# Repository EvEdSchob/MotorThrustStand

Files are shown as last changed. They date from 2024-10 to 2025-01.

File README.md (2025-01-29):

# MotorThrustStand
This motor thrust stand is an open an extensible hardware testing platform for the evaluation of small electric propulsion systems such as those used in remote control airplanes, helicopters, and drones. It was developed for implementation and use within an existing wind tunnel in the unmanned aerial vehicle laboratory at Western Michigan University by myself and my senior design partner Joshua Kraeteur.

The completed project inludes: 

- A JavaFX application comprising the user interface and data processing functionality
- KiCAD PCB design files for construction of the data capture system
- A TeensyDuino program for receiving UI commands and handling data capture and transmission
- 3D Print files for the PCB enclosure as well as mounting hardware for the pitot tubes
- A user manual with setup instructions and calibration proceedures
  
The system incorporates the following set of sensors:

- Two Pitot Tubes
- Voltage Sensor
- Current Sensor
- Tachometer
- Load Cell

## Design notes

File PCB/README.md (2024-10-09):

This folder includes the original KiCAD files for the PCB Design as well as the Gerber files used for PCB production.

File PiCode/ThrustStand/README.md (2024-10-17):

#PiCode
_A JavaFX application for controlling a Teensy 4.0 over USB serial link_

#Libraries
Built using LibericaJDK 21 LTS
Requires jSerialComm in /lib

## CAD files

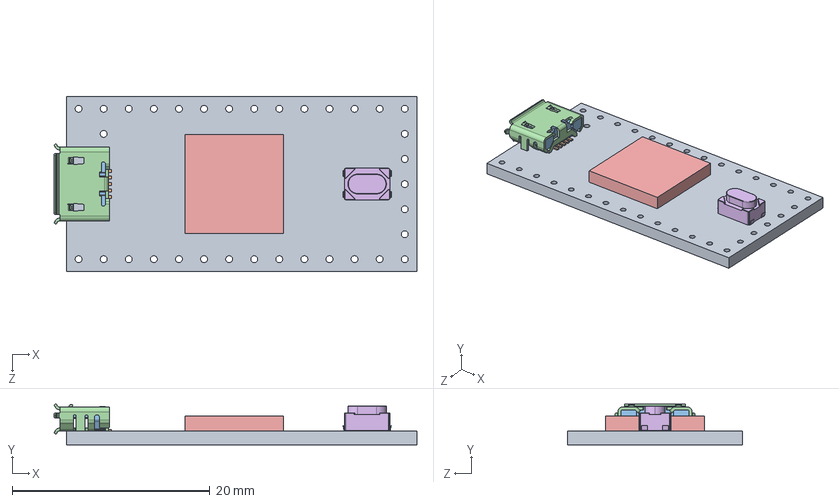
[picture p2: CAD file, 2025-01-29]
PCB/Component Libraries/teensy.pretty-master/Teensy_4.0_Assembly.STEP
36.8 x 4.12 x 17.7 mm
Teensy_4.0_PCB
Micro USB-B Female 5Pin SMD
NXP iMXRT1062
SKRPACE010 v4

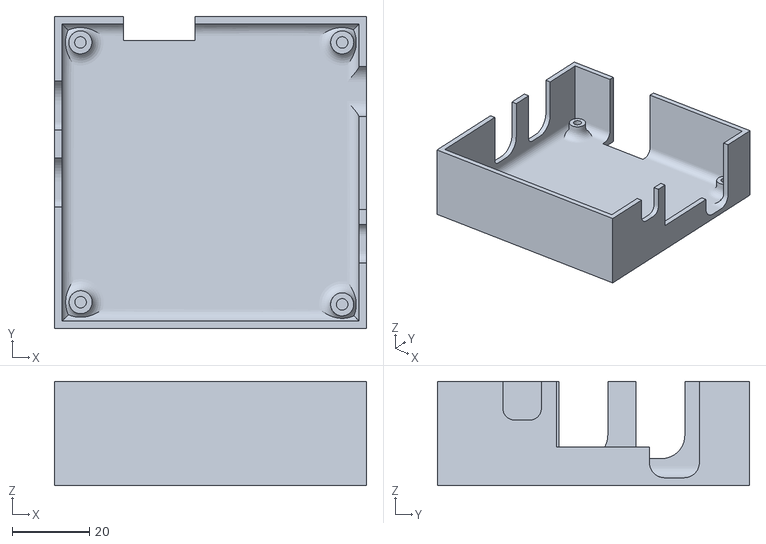
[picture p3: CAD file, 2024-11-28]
3D Print Files/Case Lower.stl
81.0 x 81.0 x 27.0

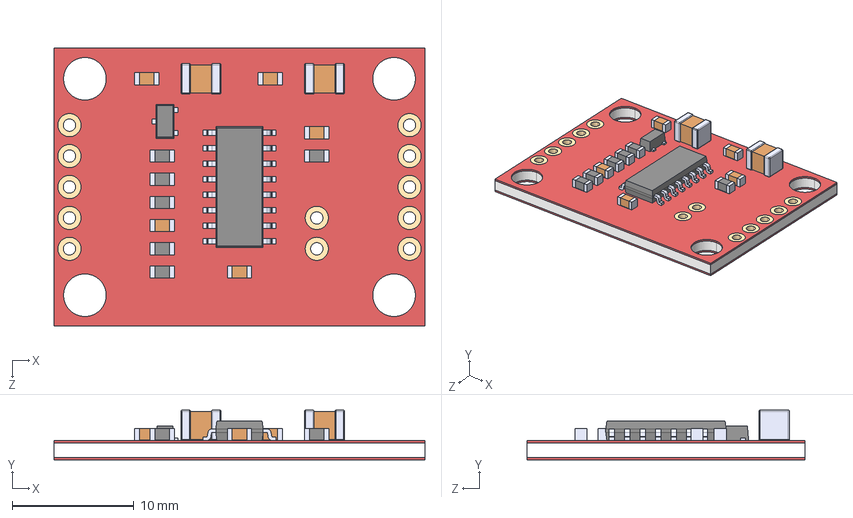
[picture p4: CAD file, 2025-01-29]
PCB/Component Libraries/SEN_13879/SEN-13879.step
30.5 x 4.10 x 22.9 mm

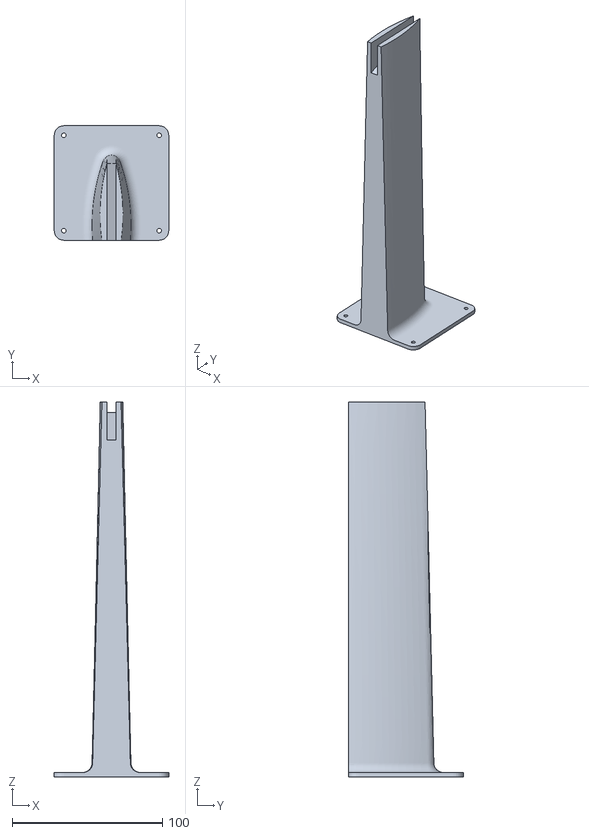
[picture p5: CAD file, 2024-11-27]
3D Print Files/Pitot Plinth Forward.stl
76.2 x 76.2 x 249.4

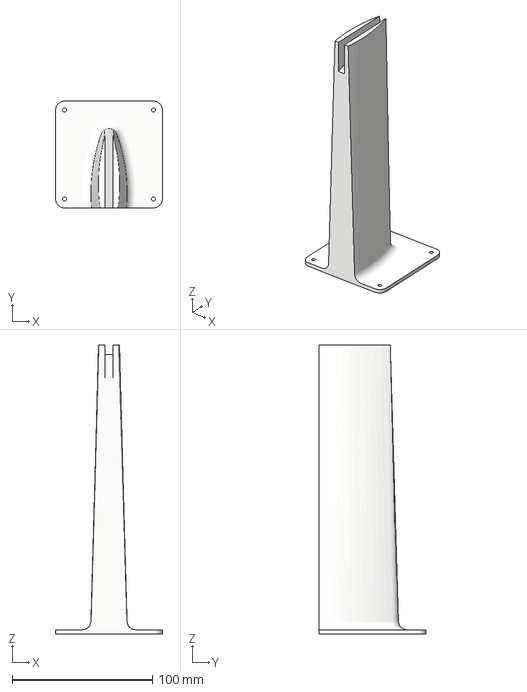
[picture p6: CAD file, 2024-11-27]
3D Print Files/Pitot Plinth Rear.3mf
76.2 x 76.2 x 206.2 mm

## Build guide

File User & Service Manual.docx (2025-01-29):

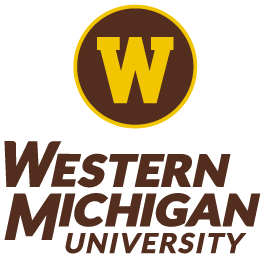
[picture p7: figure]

# Motor Thrust Stand User and Service Manual

# Hardware

Datasheets for each component are included in the Appendix

## Processing

Raspberry Pi 5

Teensy 4.0

## Sensors

Voltage Divider – A simple variable voltage divider nominally calibrated to 10:1.

Differential Pressure Sensors – Two MP3V5010DP differential pressure sensors connected to a pair of pitot-static tubes placed in the incoming and wake airflow.

Load Cell ADC – HX711 24-bit load cell amplifier breakout board from Spark Fun.

Current Sensor – One ACS758ECB-200U current sensor measuring up to 200 amperes of continuous current and capable of handling 1200 amperes of current in bursts of up to 1 second.

# Setup

## Installation

The software is provided with an installation script which will install all necessary packages and libraries. It will compile the relevant class files, download the WMU logos found on https://wmich.edu/brand/visualidentity/logo and create a desktop shortcut for the thrust stand software.

1. Download the repository from GitHub: https://github.com/EvEdSchob/MotorThrustStand
  a. Clone the repository using a git client or download it as a zip file
  b. If it was downloaded as a zip extract the file to a local folder on the Raspberry Pi
2. Navigate to the directory: MotorThrustStand/PiCode/ThrustStand in a terminal window
3. Run the command below to make the script executable sudo chmod +x thruststand-install.sh
4. Enter the command below to start the installation process sudo ./thruststand-install.sh
5. If the installer runs successfully the application can be executed in three different ways:
  a. Run the command thruststand in the terminal window. This will provide debugging output to the terminal.
  b. Click the shortcut icon on the desktop
  c. In the Raspberry Pi OS menu navigate to Accessories > ThrustStand

## Un-installing

To uninstall the software simply run: sudo ./thruststand-install.sh --uninstall

# User Interface

## Launcher

- This is the first screen shown to the user when the software launches

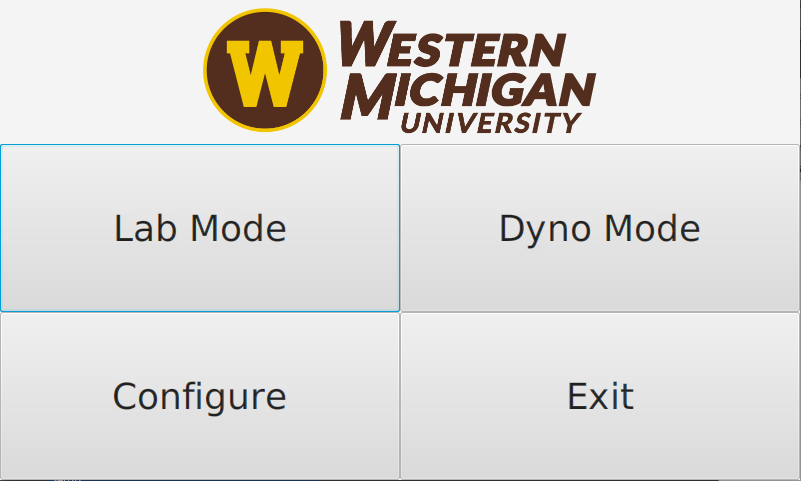
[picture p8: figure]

Figure 1: Launcher Screen

- Lab Mode – Launches the Lab Mode Screen
- Dyno Mode – Launches the Dyno Mode Screen
- Configure – Launches the Configuration Screen
- Exit – Closes the program

## Lab Mode

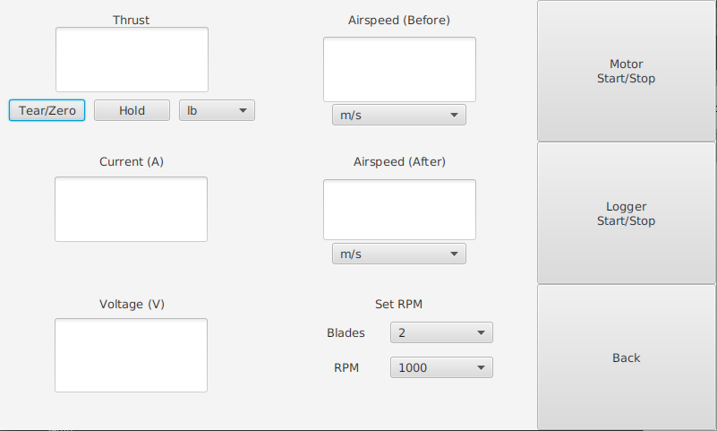
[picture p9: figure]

Figure 2: Lab Mode Screen

- Thrust – Displays the live thrust value in the selected unit
  a. Tear/Zero – “Zeroes” the thrust measurement value
  b. Hold – Freezes the user display for easy reading
  c. Units – Selects the unit of thrust measurement: Newtons, Pounds, Kilograms
- Current – Displays the live current value in Amperes
- Voltage – Displays the live voltage value in Volts
- Airspeed (Before) –
- Airspeed (After) –
- Set RPM
  d. Blades – Sets the number of blades on the propeller
  e. RPM – Sets the RPM setpoint for the PID controller on the Teensy
- Motor Start/Stop – Enables and Disables commands to the speed controller. Sets throttle to zero when disabled.
- Logger Start/Stop – Activates and Deactivates data logging. Creates a new file on disk each time it is enabled and finalizes said file when disabled.

## Dyno Mode

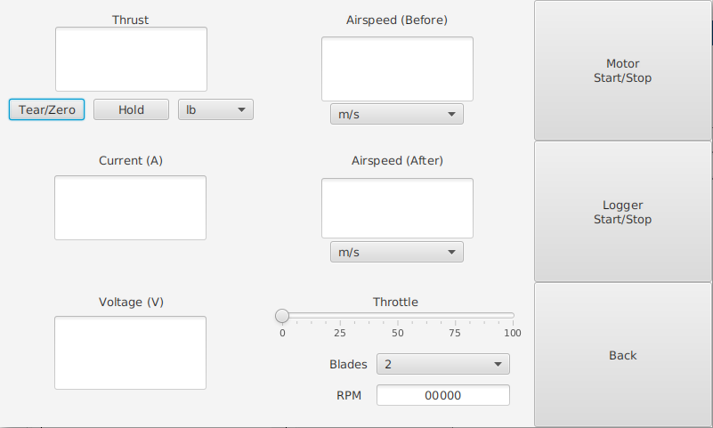
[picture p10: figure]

Figure 3: Dyno Mode Screen

- Most controls are identical to those found in Lab Mode. Refer to the Lab Mode section for details of each shared control.
- Throttle – The slider directly controls the throttle percentage between 0% and 100%
- RPM – Displays the live RPM measurement

## Configuration

- Save Calibration – Stores calibration constants for all sensors in a local file
- Load Calibration – Retrieves calibration constants from the data file
- Reset to Defaults – Loads default calibration constants from the hard-coded values
- Back – Exits the calibration screen

### Serial

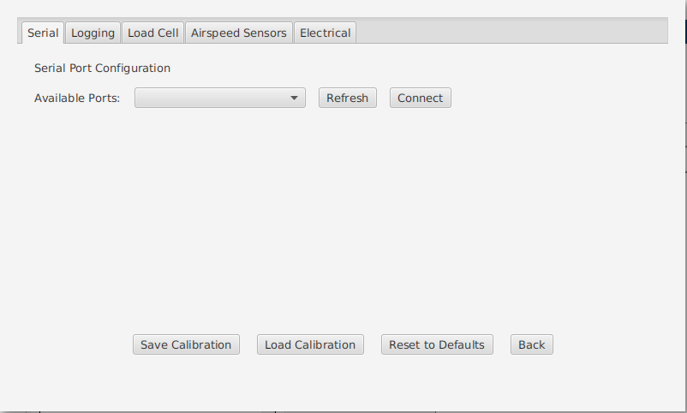
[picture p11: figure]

Figure 4: Configuration Screen - Serial Tab

- The configuration window automatically opens in the serial tab
- Ports Dropdown – Lists the available serial devices
- Refresh – Refreshes the list of serial devices
- Connect – Attempts to establish connection with the selected serial device

### Logging

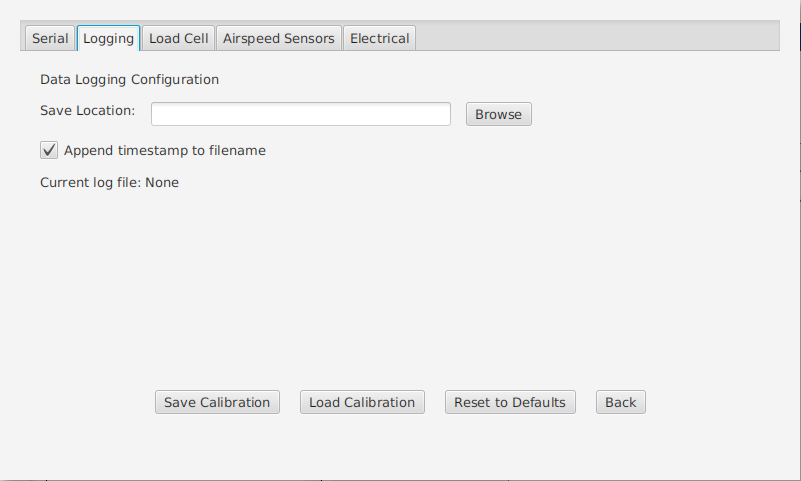
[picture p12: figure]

Figure 5: Configuration Screen - Logging Tab

- Save Location – Shows the path to the location where logging files will be saved
- Browse – Launches a directory chooser window to select where the log file will be saved
- Current log file: - Displays the name of the log file to be saved

### Load Cell

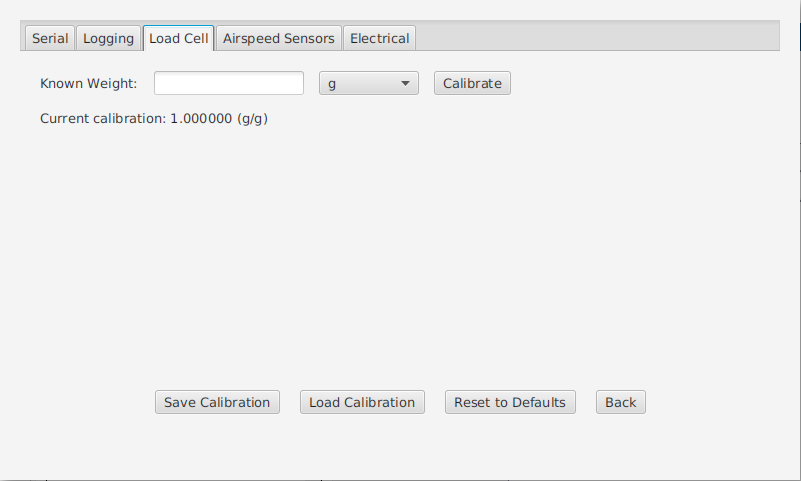
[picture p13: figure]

- Known Weight – Enter the current weight for calibration purposes
- Unit Dropdown – Selects the unit of the weight being used for calibration
- Calibrate – Calculates the new calibration constant for the load cell
- Current Calibration – Displays the current calibration constant

### Airspeed Sensors

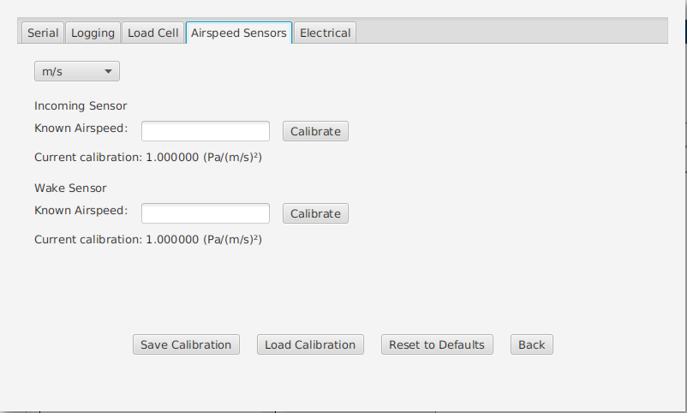
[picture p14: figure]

- Unit Dropdown – Selects the unit for airspeed calibration
- Known Airspeed – Textboxes for entering the externally measured air speed
- Calibrate – Buttons initiate the calibration constant calculation

### Electrical

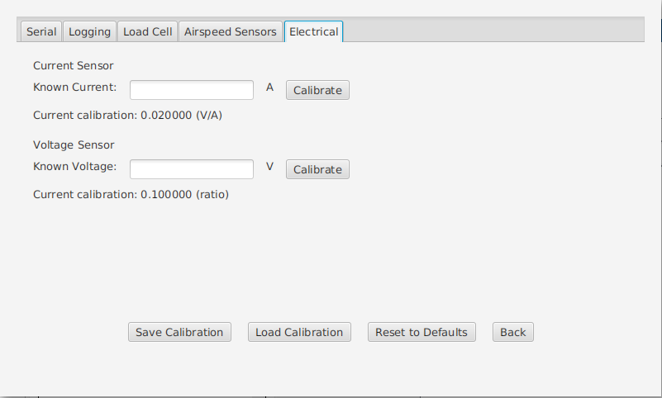
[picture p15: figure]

- Known Current – Textbox for entering the externally measured current value
- Known Voltage - Textbox for entering the externally measured voltage value
- Calibrate – Buttons initiate the calibration constant calculation

# Usage

## Startup

1. Turn on the power strip under the wind tunnel to power the device
2. Wait for the system to start up and come to the desktop
3. Launch the software:
  a. Run the command thruststand in the terminal window. This will provide debugging output to the terminal.
  b. Click the shortcut icon on the desktop
  c. In the Raspberry Pi OS menu navigate to Accessories > ThrustStand
4. Press the Configure button on the main launcher window.
5. In the Serial tab, use the drop-down menu to select the correct serial device then press the Connect button.
  a. If no device is found ensure that the USB cable is properly connected between the Teensy and the user interface then press the Refresh button.
6. (Optional) Press the Load Calibration button to load the previously saved calibration values. Skipping this step will cause the software to use the default calibration values from the software.
  a. If the system needs to be recalibrated, please see the calibration instructions on page 6.
7. (Optional) Switch to the Logging tab and browse the filesystem for a location to save the logging file. If no alternate location is selected, files will be saved to the user’s home folder. NOTE: A log file will only be created if the Logger Start/Stop button is pressed within either Lab or Dyno mode.
8. Press the Back button to return to the launcher.
9. Press the Lab Mode or Dyno Mode button to enter the desired mode.

## Shutdown

1. From either mode or the Configuration screen press the Exit button to return to the Launcher.
2. Press the Exit button on the launcher to close the ThrustStand software.
3. In the Raspberry Pi OS Menu select Shutdown… > Shutdown to halt the Raspberry Pi.
4. Turn off the power strip under the thrust stand to fully power the system down.

# Calibration

## Requirements

Before beginning calibration ensure that all of the hardware listed below is available and in working order.

- Mouse
- Keyboard
- Multimeter with DC Voltage, Resistance, and Current modes
- Current Calibration Harness
- Anemometer
- Tachometer

## Voltage Divider

1. Disconnect the USB Cable from the Teensy microcontroller in the sensor package.
2. Open sensor package case
3. Remove Teensy microcontroller
  a. This prevents damage if the input voltage is above 3.3v and the trim potentiometer is adjusted incorrectly.
4. Attach a battery or other power source to the input of the sensor package
5. Measure the input voltage by placing the positive probe of a multimeter on one leg of the current sensor and the negative probe on the ground terminal as shown in Figure 6. Record this voltage.

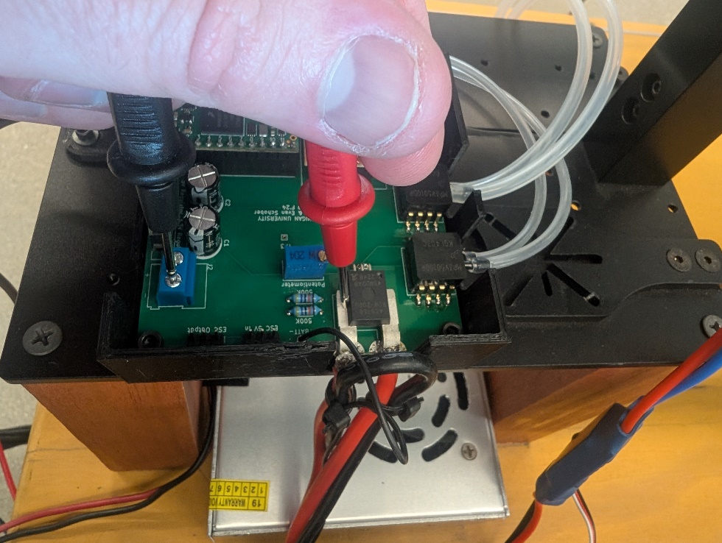
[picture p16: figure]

Figure 6: Input Voltage Measurement

6. Measure the output from the voltage divider by placing the positive probe of the multimeter on TP3 on the circuit board and the negative probe in the same location described in step 4. Record this voltage.

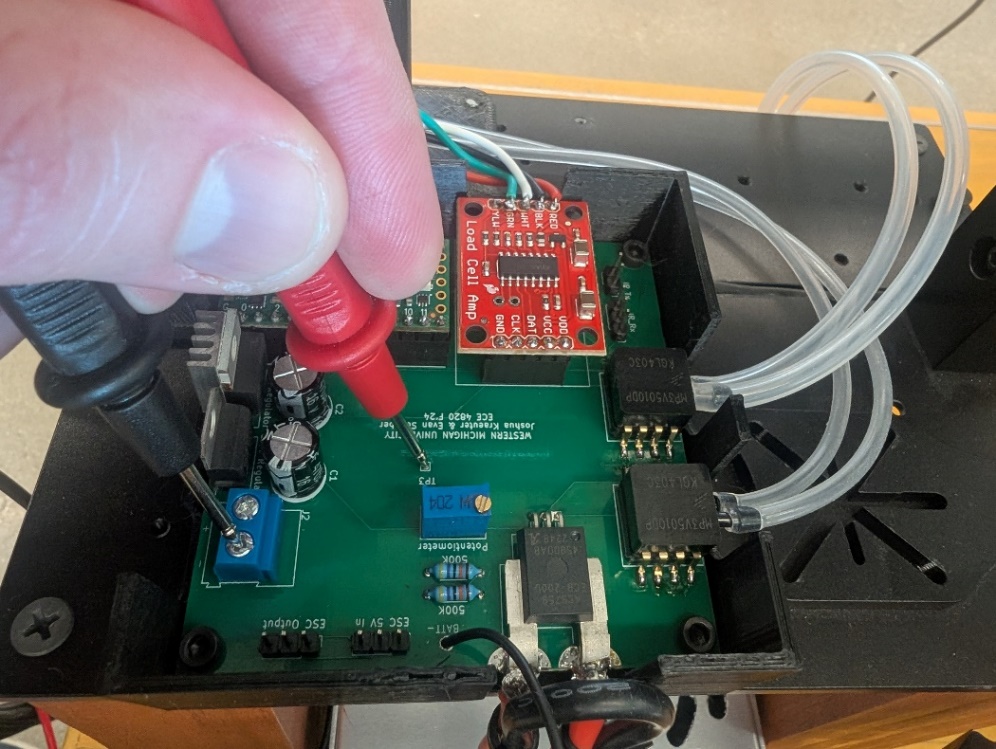
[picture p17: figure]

Figure 7: Voltage Divider Measurement

7. For a nominal configuration, (10:1 divider ratio) adjust the blue trim potentiometer so that the output voltage is one tenth of the input voltage.
  a. E.g. An input voltage of 12.19 volts results in a TP3 voltage of approximately 1.219 volts as shown below

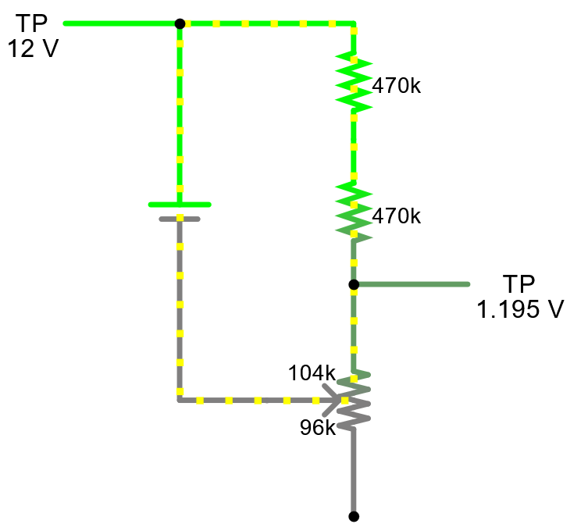
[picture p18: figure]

  b. This will allow voltages of up to 33v to be safely measured by the device.
  c. Higher voltages may be measured as necessary by re-calibrating the potentiometer for a higher divider ratio.
8. Once the trim potentiometer has been correctly adjusted, place the Teensy back into its slot with the USB port facing out.
9. Reconnect the USB cable to the micro USB port on the Teensy and one of the ports on the Pi
10. Start up the user interface and enter the Configuration menu.
11. In the Serial tab select the correct serial device and press the Connect button.
12. Switch to the Electrical tab.
13. Enter the measured battery voltage into the Known Voltage field and press the Calibrate button. This will cause the code to calculate the new divider ratio. NOTE: Please verify that the calculated value matches the expected value before continuing.
14. Press the Save Calibration button to save to the local file.

## Current Sensor

1. Start the User Interface, start the ThrustStand software and enter the Configuration mode.
2. In the Serial tab select the correct serial device from the dropdown and press the Connect button.
3. Use a multimeter in voltage mode to record the output voltage of the power source.
4. Measure the resistance of the Current Calibration Harness by connecting it to a multimeter in resistance mode with the shorting plug inserted. NOTE: It should be close to 10 ohms.

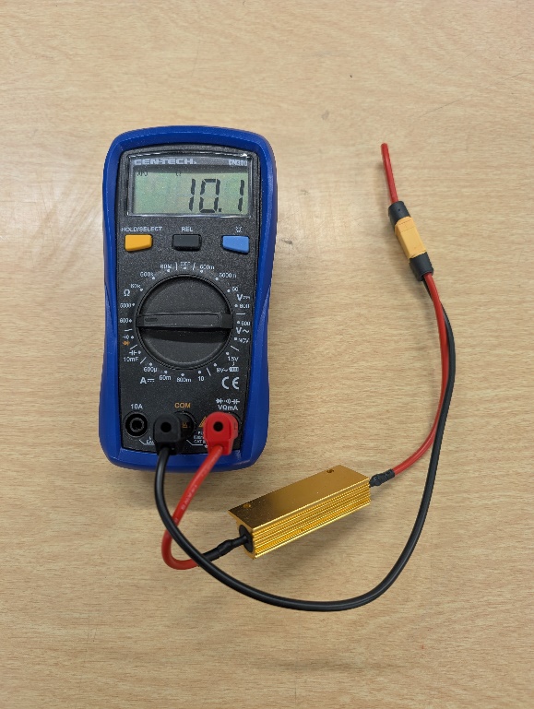
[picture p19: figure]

Figure 8: Current Harness Testing

5. Remove the shorting plug from the calibration harness and set it aside.
6. Connect the current harness to the output wire from the sensor package.

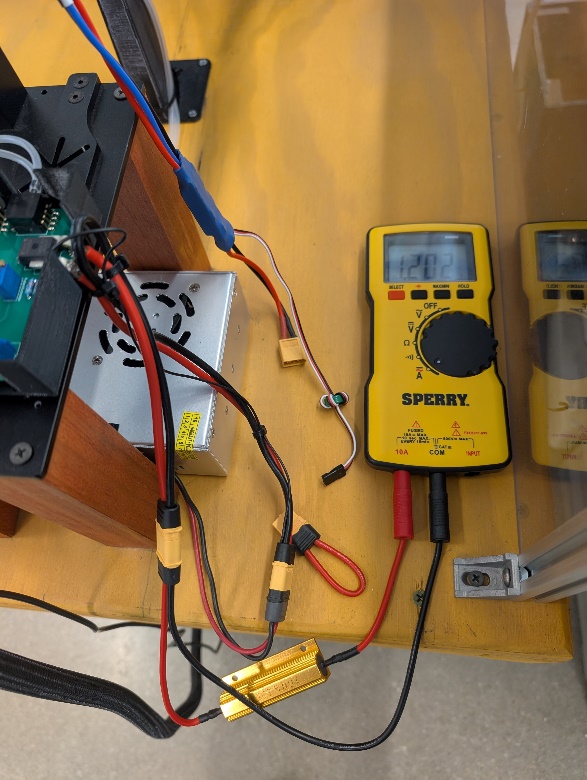
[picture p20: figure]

Figure 9: Current Calibration

7. Connect the power source to the input wire on the sensor package. NOTE: Do not leave the system connected in this configuration for extended periods of time or the resistor will become dangerously hot!
8. Enter the current value shown on the multimeter into the Known Current: field in the user interface and press the Calibrate button.
9. Press the Save Calibration button to save to the local file.
10. Disconnect the power source or the current calibration harness.

# Appendix

## Errata

1. External power is not needed for the sensor package board. The Teensy supplies sufficient voltage out through the Vin when receiving USB power to supply both regulators such that all onboard components are supplied correctly. Powering the board from the external source will cause both the 5v regulator and the Teensy to overheat.
2. There is a wire soldered to the bottom of the PCB which provides a signal ground for the voltage measurement. If this wire breaks or is removed voltage measurement will be erratic.
3. The MP3V5010DP sensor range is too great for the sensitivity of the Teensy’s ADC. These sensors have a maximum pressure differential of 1.45psi. The calculated resolution of the system is as follows:
- 2.21 meters per second
- 4.96 miles per hour
- 7.25 feet per second
- 7.95 kilometers per hour

This is the theoretical limit for the smallest measurements that can be made by the pitot system. More precise measurements would require a sensor with a narrower maximum range and/or an ADC with a higher bit-depth.

4. At present, no method exists to calibrate the RPM measurement from within the user interface.
5. An established method for calibrating the load cell has not been developed.
6. The Tear/Zero button in both Lab and Dyno mode temporarily resets the display back to the value “0” but does not “zero” the value of the load cell measurement.

## Datasheets

Datasheets for all sensors will be provided on the subsequent pages.

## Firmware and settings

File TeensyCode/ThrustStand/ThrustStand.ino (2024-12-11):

#include <Wire.h>
#include <HX711.h>

const int LED_PIN = 13; //On-board LED

//Pin Definitions
const int PITOT_FRONT = A0;
const int PITOT_REAR = A1;
const int I_SENS = A2; //Current Sensor
const int V_SENS = A3; //Voltage Sensor
const int HX711_DAT = 18;
const int HX711_CLK = 19;
const int IR_RECIV = 5;
const int ESC_PIN = 2;

//HX711 setup
HX711 loadCell;

//Speed Controller output
const float PWM_FREQ = 50.0f; //50Hz output for standard RC control
const int PWM_RES = 12; //12-bit PWM resolution
const int MIN_PULSE = 205; //~1000us at 50Hz
const int MAX_PULSE = 410; //~2000us at 50Hz

const unsigned long SEND_INTERVAL = 20; //Send interval in ms. 20ms = 1/50th of a second

//Serial control input buffer variables
String inputBuffer = "";
bool msgRDY = false;

//Serial send timer
unsigned long lastSendTime = 0;

//Tachometer variables
volatile unsigned long lastPulseTime = 0;
volatile unsigned long pulseCount = 0;
unsigned long lastRPM = 0;
const unsigned long RPM_CALC_INTERVAL = 100000; //Calculate RPM every 100ms
int numBlades = 2; //Default to 2 blade propeller
float currentRPM = 0.0;
const unsigned long RPM_TIMEOUT = 2000000; //Timeout RPM to 0 after 2 seconds

//Debounce the interrupt
const unsigned long DEBOUNCE_MICROS = 1000; //1ms debounce (May need to be shorter)
volatile unsigned long lastInterruptTime = 0;
unsigned long lastRPMcalc = 0; // Added missing variable declaration

// Global variables for control modes and PID
bool motorEnabled = false;
String currentMode = "NONE"; // Default to LAB mode
float targetRPM = 0;

// PID constants
const float KP = 0.1;  // Start conservative, tune as needed
const float KI = 0.05;
const float KD = 0.02;

// PID variables
float lastError = 0;
float integral = 0;
unsigned long lastPIDTime = 0;

void FASTRUN rpmInterrupt() {
  unsigned long currentInterruptTime = micros();
  //Debounce
  if (currentInterruptTime - lastInterruptTime > DEBOUNCE_MICROS) {
    pulseCount++;
    lastPulseTime = currentInterruptTime;
    lastInterruptTime = currentInterruptTime;
  }
}

void setup() {
  Serial.begin(2000000);

  pinMode(LED_PIN, OUTPUT);
  digitalWrite(LED_PIN, LOW);

  // Configure PWM output
  analogWriteFrequency(ESC_PIN, PWM_FREQ);
  analogWriteResolution(PWM_RES);
  
  // Set initial minimum pulse
  setESCThrottle(0);
  
  //Configure ADC
  analogReadResolution(12);

  //RPM "Trip Wire"
  pinMode(IR_RECIV, INPUT_PULLUP);
  attachInterrupt(digitalPinToInterrupt(IR_RECIV), rpmInterrupt, FALLING); 

  //Configure load cell ADC
  loadCell.begin(HX711_DAT, HX711_CLK);
  loadCell.set_gain(128);
  blinkLED(2, 100);
}

void loop() {
  unsigned long currentTime = micros();

  if(currentTime - lastRPMcalc >= RPM_CALC_INTERVAL) {
    calculateRPM(currentTime);
    lastRPMcalc = currentTime;
  }

  // Handle PID control for LAB mode
  if (currentMode == "LAB" && motorEnabled && targetRPM > 0) {
    float deltaTime = (currentTime - lastPIDTime) / 1000000.0; // Convert to seconds
    
    if (deltaTime >= 0.05) { // Update PID every 50ms
      // Calculate error
      float error = targetRPM - currentRPM;
      
      // Calculate integral term with anti-windup
      integral = constrain(integral + (error * deltaTime), -20, 20);
      
      // Calculate derivative term
      float derivative = (error - lastError) / deltaTime;
      
      // Calculate PID output
      float output = (KP * error) + (KI * integral) + (KD * derivative);
      
      // Convert PID output to throttle percentage
      int throttle = constrain(output, 0, 100);
      
      // Update variables for next iteration
      lastError = error;
      lastPIDTime = currentTime;
      
      // Set the throttle
      setESCThrottle(throttle);
    }
  } 

  checkForMSG(); //Read serial for command

  if (msgRDY) {
    processMSG();
    msgRDY = false;
    inputBuffer = "";
  }

  //Send sensor data on send interval
  if (currentTime - lastSendTime >= SEND_INTERVAL * 1000) {
    sendData();
    lastSendTime = currentTime;
  }
}

void calculateRPM(unsigned long currentTime) {
  noInterrupts();
  unsigned long localLastPulseTime = lastPulseTime;
  unsigned long localPulseCount = pulseCount;
  pulseCount = 0;
  interrupts();
  
  if(currentTime - localLastPulseTime > RPM_TIMEOUT) {
    currentRPM = 0;
    return;
  }

  float minutesFrac = (float)RPM_CALC_INTERVAL / 60000000.0;
  currentRPM = (localPulseCount / (float)numBlades) / minutesFrac;
}

void checkForMSG() {
  while (Serial.available()) {
    char inChar = (char)Serial.read();
    if(inChar == '\n') {
      msgRDY = true;
      return;
    }
    inputBuffer += inChar;
  }
}

void processMSG() {
  //Find the position of the colon
  int colonPos = inputBuffer.indexOf(':');
  if (colonPos == -1) {
      //No colon found, invalid command
      return;
  }

  //Split into command and value
  String cmd = inputBuffer.substring(0, colonPos);
  String value = inputBuffer.substring(colonPos + 1);
  
  //Remove whitespace characters
  cmd.trim();
  value.trim();

  if (cmd.equals("MOTOR")) {
    if (value.equals("ON")) {
      blinkLED(1, 50);
      motorEnabled = true;
    } else if (value.equals("OFF")) {
      motorEnabled = false;
      setESCThrottle(0); // Safety: disable motor output
    }
  }
  else if (cmd.equals("THR")) {
    if (motorEnabled) {  // Only check if motor is enabled
      int throttle = value.toInt();
      setESCThrottle(throttle);
    }
  }
  else if (cmd.equals("MODE")) {
    currentMode = value;
    // Reset control variables when switching modes
    integral = 0;
    lastError = 0;
    targetRPM = 0;
    setESCThrottle(0); // Safety: set throttle to 0 when changing modes
  }
  else if (cmd.equals("BLAD")) {
    numBlades = value.toInt();
  }
  else if (cmd.equals("RPM")) {
    if (currentMode == "LAB") {
      targetRPM = value.toFloat();
    }
  }
}

void setESCThrottle(int throttlePercent) {
  throttlePercent = constrain(throttlePercent, 0, 100);
  int pulseWidth = map(throttlePercent, 0, 100, 1000, 2000);
  
  float period = 1000000.0f / PWM_FREQ;
  float dutyCycle = float(pulseWidth) / period;
  int pwmValue = (dutyCycle * (1 << PWM_RES));
  
  analogWrite(ESC_PIN, pwmValue);
}

void sendData() {
  float pitot1 = readVoltage(PITOT_FRONT);
  float pitot2 = readVoltage(PITOT_REAR);
  float current = readVoltage(I_SENS);
  float voltage = readVoltage(V_SENS);
  long rawLoadCell = loadCell.read();

  String dataPackage = packageData(pitot1, pitot2, current, voltage, rawLoadCell, currentRPM);
  Serial.println(dataPackage);
}

float readVoltage(int pin) {
  int rawValue = analogRead(pin);
  return (rawValue / 4095.0) * 3.3;
}

String packageData(float pitot1, float pitot2, float current, float voltage, long rawLoadCell, float rpm) {
  return String(pitot1, 3) + "," + String(pitot2, 3) + "," + 
         String(current, 3) + "," + String(voltage, 3) + "," +
         String(rawLoadCell) + "," + String(rpm, 1);
}

//Blinks LED for debugging purposes
void blinkLED(int times, int delayMs) {
  for(int i = 0; i < times; i++) {
    digitalWrite(LED_PIN, HIGH);
    delay(delayMs);
    digitalWrite(LED_PIN, LOW);
    delay(delayMs);
  }
}

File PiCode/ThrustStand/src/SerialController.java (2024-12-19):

/*  Title:  SerialController.Java
 *  Author: Evan Schober
 *  Email:  evan.e.schober@wmich.edu
 *  Parent Class: ThrustStand.java
 *  Description: 
 *  
 */
import com.fazecast.jSerialComm.SerialPort;
import com.fazecast.jSerialComm.SerialPortEvent;
import com.fazecast.jSerialComm.SerialPortMessageListener;
import javafx.application.Platform;

import java.nio.charset.StandardCharsets;
import java.util.ArrayList;
import java.util.List;
import java.util.function.Consumer;
import java.util.Arrays;

public class SerialController {
    private static SerialController instance;
    private SerialPort serialPort;
    private List<Consumer<String>> dataReceivedListeners = new ArrayList<>();

    // Data indices for parsing CSV
    private static final int PITOT1_INDEX = 0;
    private static final int PITOT2_INDEX = 1;
    private static final int CURRENT_INDEX = 2;
    private static final int VOLTAGE_INDEX = 3;
    private static final int LOADCELL_INDEX = 4;
    private static final int RPM_INDEX = 5;

    // Command prefixes for sending to Teensy
    private static final String CMD_SET_THROTTLE = "THR:";  // THR:50 for 50% throttle
    private static final String CMD_SET_MODE = "MODE:";     // MODE:LAB or MODE:DYNO
    private static final String CMD_SET_BLADES = "BLADE:";  // BLADE:2 for 2 blades
    private static final String CMD_MOTOR = "MOTOR:";       // MOTOR:ON or MOTOR:OFF
    private static final String CMD_SET_RPM = "RPM:";          // RPM:1000 for target RPM
    
    
    private SerialController() {}

    public static SerialController getInstance(){
        if(instance == null){
            instance = new SerialController();
        }
        return instance;
    }

    //Public method for opening a given serial port
    public boolean openPort(String portName, int buadRate){
        serialPort = SerialPort.getCommPort(portName);
        serialPort.setBaudRate(buadRate);
        serialPort.setNumDataBits(8);
        serialPort.setNumStopBits(1);
        serialPort.setParity(SerialPort.NO_PARITY);

        if(serialPort.openPort()){
            //System.out.println("Connection with " + serialPort.getSystemPortName() + " opened successfully!"); //Debug
            addDataListener();
            return true;
        } else {
            //System.out.println("Connection with " + serialPort.getSystemPortName() + " failed to open!"); //Debug
            return false;
        }
    }

    //Public method for closing a serial port
    public void closePort(){
        if (serialPort != null && serialPort.isOpen()) {
            serialPort.closePort();
            System.out.println("Closed port: " + serialPort.getSystemPortName());
        }
    }

    private boolean sendData(String data) {
        if(serialPort != null && serialPort.isOpen()) {
            byte[] bytes = data.getBytes(StandardCharsets.UTF_8);
            int bytesWritten = serialPort.writeBytes(bytes, bytes.length);
            if(bytesWritten == -1) {
                System.err.println("Failed to write data to serial port");
                return false;
            } else {
                System.out.println("Sent: " + data.trim());
                return true;
            }
        } else {
            System.err.println("Serial port is not open");
            return false;
        }
    }

    public void addDataReceivedListener(Consumer<String> listener){
        dataReceivedListeners.add(listener);
    }

    public void removeDataReceivedListner(Consumer<String> listener){
        dataReceivedListeners.remove(listener);
    }


    //Internal method to create a data listener
    private void addDataListener() {
        serialPort.addDataListener(new SerialPortMessageListener() {
            @Override
            public int getListeningEvents() { return SerialPort.LISTENING_EVENT_DATA_RECEIVED; }

            @Override
            public byte[] getMessageDelimiter() { return new byte[] { (byte)'\n' }; }

            @Override
            public boolean delimiterIndicatesEndOfMessage() { return true; }

            @Override
            public void serialEvent(SerialPortEvent event) {
                byte[] newData = event.getReceivedData();
                String message = new String(newData, StandardCharsets.UTF_8).trim();
                Platform.runLater(() -> {
                    for (Consumer<String> listener : dataReceivedListeners) {
                        listener.accept(message);
                    }
                });
            }
        });
    }

    public String[] getAvailablePorts() {
        return Arrays.stream(SerialPort.getCommPorts())
                .map(SerialPort::getSystemPortName)
                .toArray(String[]::new);
    }

    // Method to parse received data
    public void parseData(String data) {
        try {
            String[] values = data.trim().split(",");
            if (values.length == 6) {  // Verify we got all expected values
                float pitot1 = Float.parseFloat(values[PITOT1_INDEX]);
                float pitot2 = Float.parseFloat(values[PITOT2_INDEX]);
                float current = Float.parseFloat(values[CURRENT_INDEX]);
                float voltage = Float.parseFloat(values[VOLTAGE_INDEX]);
                long loadCell = Long.parseLong(values[LOADCELL_INDEX]);
                float rpm = Float.parseFloat(values[RPM_INDEX]);
                
                // Now update UI elements through SharedElements
                SharedElements.getInstance().updateMeasurements(
                    loadCell,    // You'll need to convert raw value to actual units
                    pitot1,      // Convert voltage to airspeed
                    pitot2,      // Convert voltage to airspeed
                    current,     // Convert to actual current
                    voltage,     // Convert to actual voltage
                    rpm
                );
            }
        } catch (NumberFormatException e) {
            System.err.println("Error parsing data: " + data);
            e.printStackTrace();
        }
    }

    // Methods to send commands to Teensy
    public boolean setThrottle(int percentage) {
        return sendData(String.format(CMD_SET_THROTTLE + percentage + "\n"));
    }

    public boolean setMode(String mode) {
        if (mode.equals("LAB") || mode.equals("DYNO")) {
            return sendData(CMD_SET_MODE + mode + "\n");
        }
        return false;
    }

    public boolean setBladeCount(int blades) {
        return sendData(CMD_SET_BLADES + blades + "\n");
    }

    public boolean setMotor(boolean on) {
        return sendData(CMD_MOTOR + (on ? "ON" : "OFF") + "\n");
    }

    public boolean setRPM(int rpm) {
        return sendData(CMD_SET_RPM + rpm + "\n");
    }
}

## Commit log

2024-10-11 Add FXML files for Dyno and Lab modes and create basic views. Add controller class for Launcher and modify to interface with Launcher.fxml. Modify ThrustStand.java to init Launcher controller. Modify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
2024-10-17 Add BaseController abstract class. Remove redundant serial error handling.
    [DynoMode.java, LabMode.java]
2024-10-23 Add basic sensor and serial code.
2024-10-25 Add method for reading voltage
2024-11-02 Add parsing and coommand functions to serial controller. Add event handlers to lab and dyno modes. Modify configuration scene to handle sensor calibration.
2024-11-08 Modify ThrustStand.ino for PID
2024-11-15 Correct current calculation and thrust hold toggle
    [DynoMode.java, LabMode.java, SharedElements.java]
2024-11-15 Enable throttle control. Fix hold button behavior
    [DynoMode.java, LabMode.java, SharedElements.java]
2024-11-20 Adjust default Voltage Divider Ratio. Implement calibration button handler.
2024-11-23 Switched lab and dyno tags for correct operation
    [ThrustStand.ino]
2024-11-23 Fix voltage handling for calibration menu
    [SharedElements.java]
2024-11-27 Upload Rear Pitot Plinth
    [Pitot Plinth Rear.3mf]
2024-11-27 Add forward pitot plinth
    [Pitot Plinth Forward.stl]
2024-11-27 Updates for testing throttle control
2024-11-27 Simplified throttle control commands
2024-11-28 Simplify command structure to validate throttle handing
2024-11-28 Modify throttle commands to match simplified structure
2024-11-28 Add STL of lower case half
    [Case Lower.stl]
2024-12-03 Update calibration methods to use raw values
2024-12-03 Update throttle to only send final position of throttle slider.
2024-12-10 Clean up Teensy code comments
2024-12-11 Fix current sensor values to match real-world values
    [LabMode.java, SharedElements.java]
2024-12-11 Corrected current calibration values
    [SharedElements.java]
2024-12-12 Update airspeed calibration to properly handle sensor sensitivity
2024-12-18 Modify thrust calibration proceedure
2024-12-18 Simplify calibration defualt handling. Update loadcell calibration constants using emperical values.
2024-12-18 Update airspeed calibration
2024-12-18 Improve current calibration method
2024-12-18 Complete current calibration method
2024-12-19 Disable debug output. Fix current calibration.
    [DynoMode.java, LabMode.java, SerialController.java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]
2025-01-29 Add PCB files and User Manual
    [Adafruit ADS1015 ADC STEMMA QT.brd, Adafruit ADS1015 ADC STEMMA QT.sch, Adafruit ADS1115 ADC STEMMA QT.brd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]
